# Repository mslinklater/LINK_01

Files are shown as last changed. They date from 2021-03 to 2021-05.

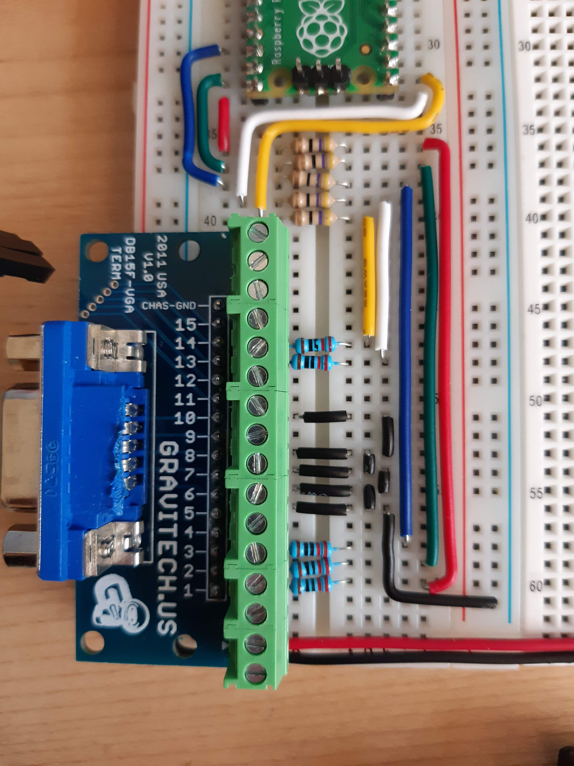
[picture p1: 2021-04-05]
images/20210330_164638.jpg

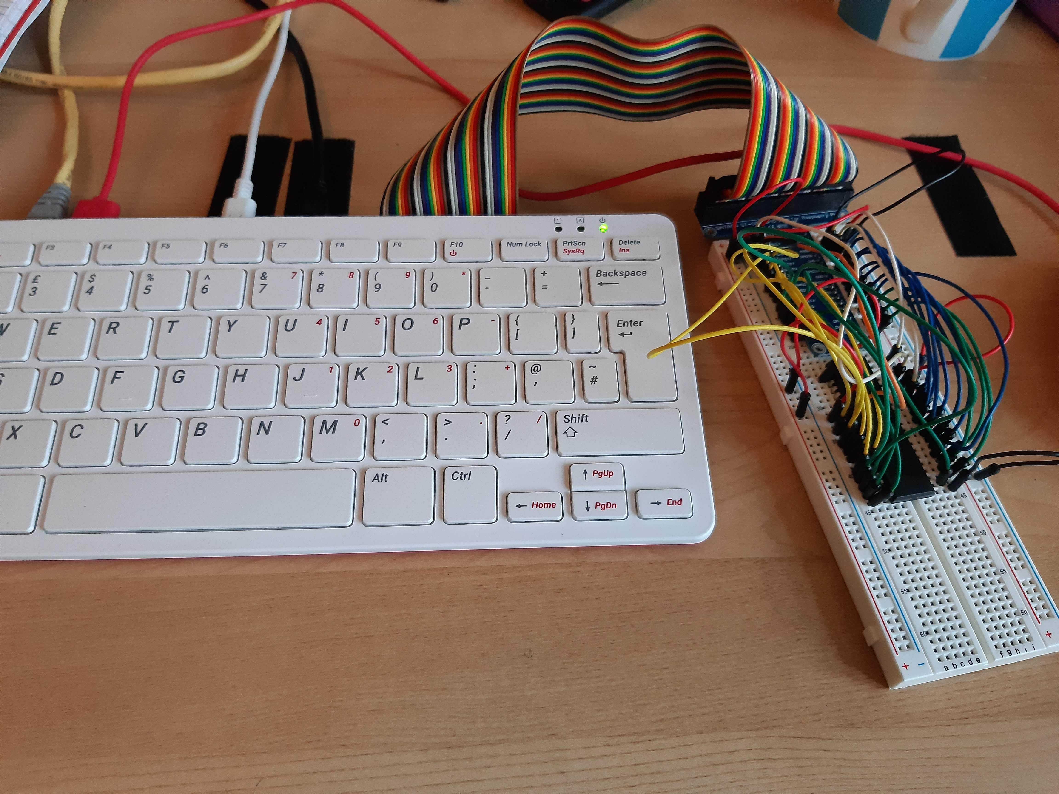
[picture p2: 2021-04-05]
images/20210210_091011.jpg

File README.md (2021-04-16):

# LINK_01
The LINK_01 machine

## What is LINK_01 ?

LINK_01 is my first hombrew computer. At the moment I'm not sure it will work... but I hope it will.

## Key Features

* To explore 8-bit CPU technology by leveraging modern cheap microcontrollers.
* To be fully software upgradeable
* To let the microcontroller do the heavy lifting with I/O
* To use modern compiler and debugging tools
* To have fun programming the 6502

# Starting the monitor

> minicom -b 115200 -o -D /dev/serial0

ctrl-a q to quit

# Writing the EEPROM

> minipro -p AT28C64B -w ROMFILE

# Outputting a ROM

> hexdump -C FILE

# Raspberry Pi pins

|pin|use|
|---|---|
|6|GND (board)|
|8|UART-TX|
|10|UART-RX|
|18|SWDIO|
|20|GND|
|22|SWCLK|

# Pico pins

|use|GPIO|pin||pin|GPIO|use|
|---|---|---|---|---|---|---|
|UART TX|0|1|###|40|-|5V IN|
|UART RX|1|2|###|39|-||
|GND|-|3|###|38|-|GND|
||2|4|###|37|-||
||3|5|###|36|-||
||4|6|###|35|-||
||5|7|###|34|28|6502 PHI-2|
|GND|-|8|###|33|-|GND|
||6|9|###|32|27|6502 RESB|
||7|10|###|31|26|6502 BE|
||8|11|###|30|-||
||9|12|###|29|22|6502 IRQB|
|GND|-|13|###|28|-|GND|
|6502 RWB|10|14|###|27|21|6502 NMIB|
|SHIFTER OUT|11|15|###|26|20|SHIFTER OE|
|SHIFTER IN|12|16|###|25|19|SHIFTER S0|
|VGA-B|13|17|###|24|18|SHIFTER S1|
|GND|-|18|###|23|-|GND|
|VGA-G|14|19|###|22|17|VGA v-sync|
|VGA-R|15|20|###|21|16|VGA h-sync|

Pin counts (available 28)

UART 2
VGA 5
6502 5
Shifter 5

# VGA pins

|pin|use|
|---|---|
|1|R|
|2|G|
|3|B|
|4|-|
|5|GND|
|6|GND|
|7|GND|
|8|GND|
|9|-|
|10|GND|
|11|-|
|12|-|
|13|H-SYNC|
|14|V-SYNC|
|15|-|

# 65c02 pins

|use|pin||pin|use|
|---|---|---|---|---|
|VPB|1|XXX|40|RESB|
|RDY|2|XXX|39|PHI2O|
|PHI1O|3|XXX|38|SOB|
|IRQB|4|XXX|37|PHI2|
|MLB|5|XXX|36|BE|
|NMIB|6|XXX|35|NC|
|SYNC|7|XXX|34|RWB|
|VDD|8|XXX|33|D0|
|A0|9|XXX|32|D1|
|A1|10|XXX|31|D2|
|A2|11|XXX|30|D3|
|A3|12|XXX|29|D4|
|A4|13|XXX|28|D5|
|A5|14|XXX|27|D6|
|A6|15|XXX|26|D7|
|A7|16|XXX|25|A15|
|A8|17|XXX|24|A14|
|A9|18|XXX|23|A13|
|A10|19|XXX|22|A12|
|A11|20|XXX|21|VSS|

# Voltage Shifter 1 - TSX0108E

|pin|function|
|---|---|
|1|6502 PHI2|
|2|6502 RESB|
|3|6502 BE|
|4|6502 IRQB|
|5|6502 NMIB|
|6|SHIFTER OE|
|7|SHIFTER S0|
|8|SHIFTER S1|

# Voltage Shifter 2 - TSX0108E

|pin|function|
|---|---|
|1|SHIFTER IN|
|2|SHIFTER OUT|
|3|6502 RWB|
|4||
|5||
|6||
|7||
|8||

# Shift register - SN74F299N

|use|pin|---|pin|use|
|---|---|---|---|---|
||1|###|20||
||2|###|19||
||3|###|18||
||4|###|17||
||5|###|16||
||6|###|15||
||7|###|14||
||8|###|13||
||9|###|12||
||10|###|11||

# AT28C64B EEPROM

|pin|num|---|num|pin|
|---|---|---|---|---|
|NC|1|###|28|VCC|
|A12|2|###|27|~WE|
|A7|3|###|26|NC|
|A6|4|###|25|A8|
|A5|5|###|24|A9|
|A4|6|###|23|A11|
|A3|7|###|22|~OE|
|A2|8|###|21|A10|
|A1|9|###|20|~CE|
|A0|10|###|19|I/O7|
|I/O0|11|###|18|I/O6|
|I/O1|12|###|17|I/O5|
|I/O2|13|###|16|I/O4|
|GND|14|###|15|I/O3|

# AS6C6264 8K RAM

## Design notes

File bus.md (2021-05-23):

# 5V Bus

|ID|Count|Description|
|---|---|---|
|GND|1|Ground 0V - VDD|
|5V|1|5V Supply - VCC|
|A0-A15|16|Address lines 0-15|
|D0-D7|8|Data lines 0-7|
|R/~W|1|Rear/Write - from 6502 or Pico|
|~R|1|Read pulse|
|~W|1|Write pulse|
|CLK|1|Clock - from Pico|
|RESET|1|6502 Reset - from Pico|
|NMIB|1|Non-maskable interrupt - pulled up|
|IRQB|1|Interrupt request - pulled up|
|FREE|3|Left to assign|
|TOTAL|36|Max lines on the veroboard|

If things become tight the ~R and ~W channels could be retired. This would mean those signals would need to be generated locally per module rather than as part of the 6502 module.

# 3V3 Bus

|ID|Count|Description|
|---|---|---|
|GND|1|Ground 0V VDD|
|3V3|1|3.3V Supply VCC|
|B0-B15|16|General purpose signals|
|TOTAL|18||

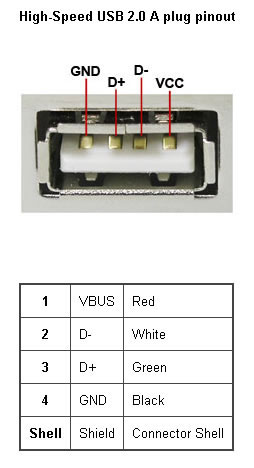
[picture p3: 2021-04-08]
schematics/chips/USB-A-TERM_4.jpg

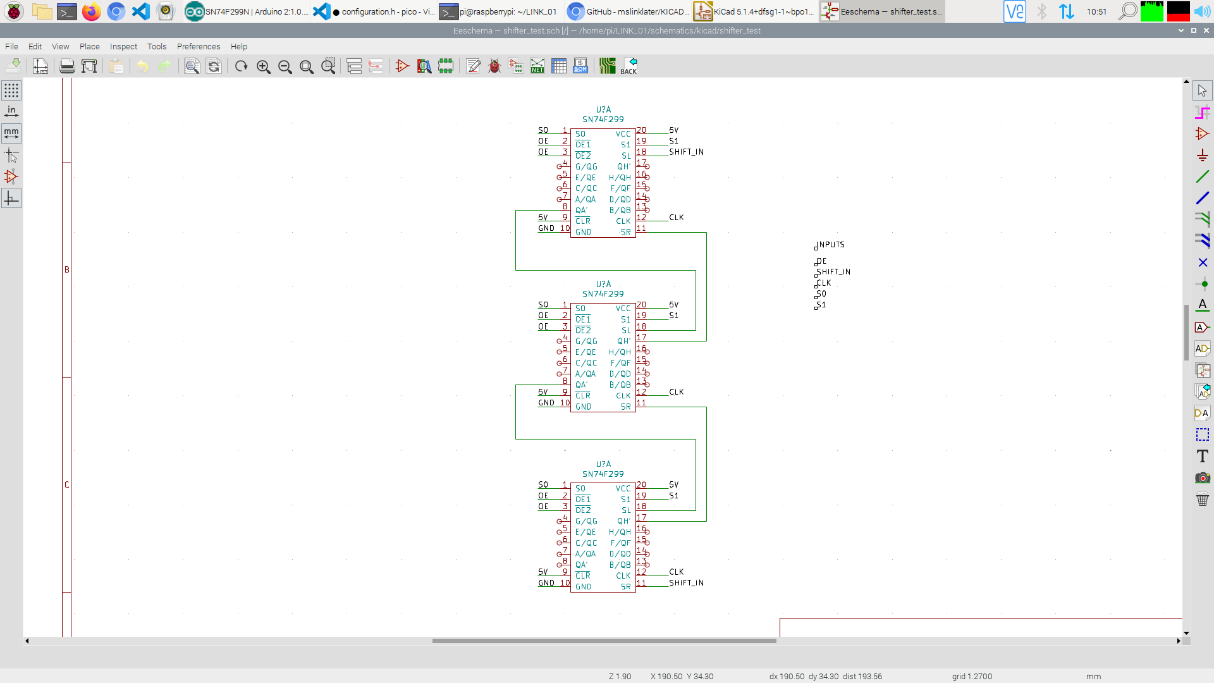
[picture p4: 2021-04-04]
images/shifter.png

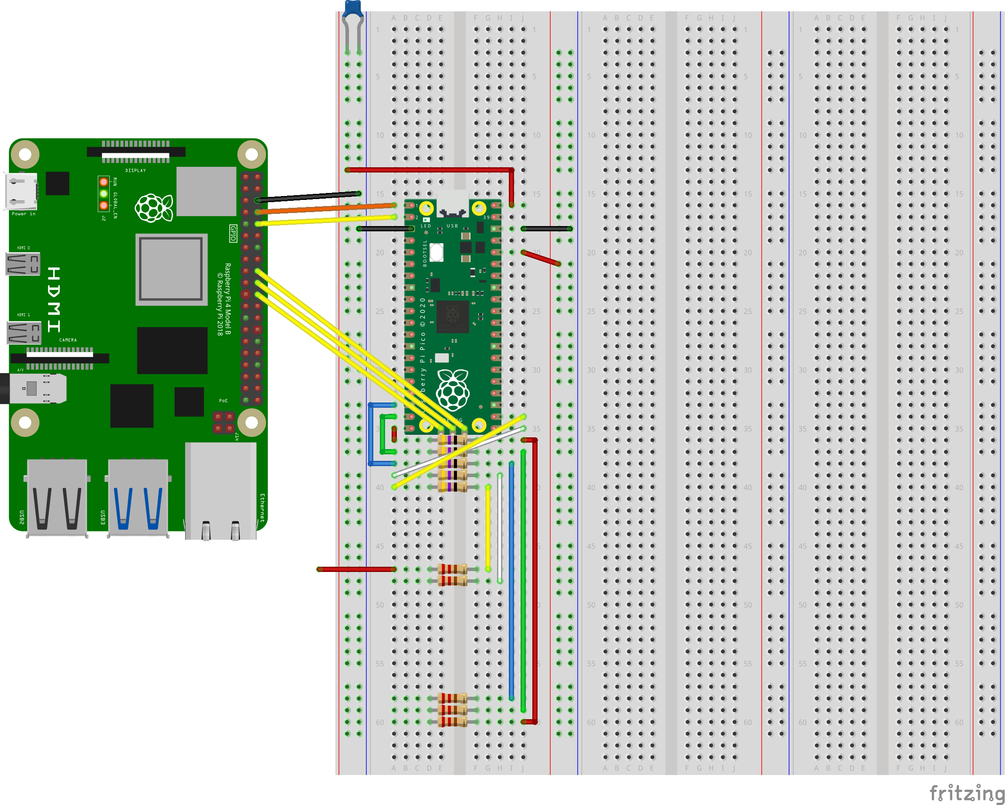
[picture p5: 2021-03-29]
images/LINK_01_bb.png

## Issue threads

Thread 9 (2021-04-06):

Fix UART comms

mslinklater, 2021-04-06:
No idea why it's stopped working. Sample programs are also hosed so probably a hardware thing.

mslinklater, 2021-04-16:
UART is working but not doing line feeds... printf is though.. scope them and find the difference,.

Closed 2021-04-30.

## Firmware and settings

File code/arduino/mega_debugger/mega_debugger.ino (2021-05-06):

#include <LiquidCrystal.h>

#define NUM_READ_PINS 32
#define NUM_DELAY_VALUES 4
#define NUM_DISPLAY_MODES 2
#define NUM_BUTTONS 3
#define BUTTON_DEBOUNCE 50
#define CLOCK_PIN 2

#define LCD_RS 8
#define LCD_EN 9
#define LCD_D4 10
#define LCD_D5 11
#define LCD_D6 12
#define LCD_D7 13

const String mnemonics[256] = {
  "BRK", "ORA(zp,x)", "", "", "TSB zp", "ORA zp", "ASL zp", "RMB0 zp", "PHP", "ORA #", "ASL A", "", "TSB a", "ORA $", "ASL $", "BBR0 r",
  "BPL r", "ORA (zp),y", "ORA (zp)", "", "TRB zp", "ORA zp,x", "ASL zp,x", "RMB1 zp", "CLC", "ORA $,y", "INC A", "", "TRB $", "ORA $,x", "ASL $,x", "BBR1 r",
  "JSR a", "AND (zp,x)", "", "", "BIT zp", "AND zp", "ROL zp", "RMB2 zp", "PLP", "AND #", "ROL A", "", "BIT $", "AND $", "ROL $", "BBR2 r",
  "BMI r", "AND (zp),y", "AND (zp)", "", "BIT zp,x", "AND zp,x", "ROL zp,x", "RMB3 zp", "SEC I", "AND $,y", "DEC A", "", "BIT $,x", "AND $,x", "ROL $,x", "BBR3 r",
  "RTI s", "EOR (zp,x)", "", "", "", "EOR zp", "LSR zp", "RMB4 zp", "PHA", "EOR #", "LSR A", "", "JMP $", "EOR $", "LSR $", "BBR4 r",
  "BVC r", "EOR (zp),y", "EOR (zp)", "", "", "EOR zp,x", "LSR zp,x", "RMB5 zp", "CLI", "EOR $,y", "PHY", "", "", "EOR $,x", "LSR $", "BBR5 r",
  "RTS s", "ADC (zp,x)", "", "", "STZ zp", "ADC zp", "ROR zp", "RMB6 zp", "PLA", "ADC #", "ROR A", "", "JMP ($)", "ADC $", "ROR $", "BBR6 r",
  "BVS r", "ADC (zp),y", "ADC (zp)", "", "STZ zp,x", "ADC zp,x", "ROR zp,x", "RMB7 zp", "SEI", "ADC $,y", "PLY", "", "JMP ($.x)", "ADC $,x", "ROR $,x", "BBR7 r",
  "BRA r", "STA (zp,x)", "", "", "STY zp", "STA zp", "STZ zp", "SMB0 zp", "DEY", "BIT #", "TXA", "", "STY $", "STA $", "STX $", "BBS0 r",
  "BCC r", "STA (zp),y", "STA (zp)", "", "STY zp,x", "STA zp,x", "STZ zp,y", "SMB1 zp", "TYA", "STA $,y", "TSX", "", "STZ $", "STA $,x", "STZ $,x", "BBS1 r",
  "LDY #", "LDA (zp,x)", "LDX #", "", "LDY zp", "LDA zp", "LDX zp", "SMB2 zp", "TAY", "LDA #", "TAX", "", "LDY $", "LDA $", "LDX $", "BBS2 r",
  "BCS r", "LDA (zp),y", "LDA (zp)", "", "LDY zp,x", "LDA zp,x", "LDX zp,y", "SMB3 zp", "CLV", "LDA A,y", "TSX", "", "LDY $,x", "LDA $,x", "LDX $,x", "BBS3 r",
  "CPY #", "CMP (zp,x)", "", "", "CPY zp", "CMP zp", "DEC zp", "SMB4 zp", "INY", "CMP #", "DEX", "WAI", "CPY $", "CMP $", "DEC $", "BBS4 r",
  "BNE r", "CMP (zp),y", "CMP (zp)", "", "", "CMP zp,x", "DEC zp,x", "SMB5 zp", "CLD", "CMP $,y", "PHX", "STP", "", "CMP $,x", "DEC $,x", "BBS5 r",
  "CPX #", "SBC (zp,x)", "", "", "CPX zp", "SBC zp", "INC zp", "SMB6 zp", "INX", "SBC #", "NOP", "", "CPX $", "SBC $", "INC $", "BBS6 r",
  "BEQ r", "SBC (zp),y", "SBC (zp)", "", "", "SBC zp,x", "INC zp,x", "SMB7 zp", "SED", "SBC $,y", "PLX", "", "", "SBC $,x", "INC $,x", "BBS7 r"
};

const String symbolfile = "";

// input pins
const int read_pins[NUM_READ_PINS] = { 
  23, 25, 27, 29, 31, 33, 35, 37,
  39, 41, 43, 45, 47, 49, 51, 53,
  22, 24, 26, 28, 30, 32, 34, 36,
  38, 40, 42, 44, 46, 48, 50, 52 };

#define RW_PIN 24
#define SYNC_PIN 25
#define CPU_BE_PIN 26

int cached_read_pins[NUM_READ_PINS];

// button pins
const int button_pins[NUM_BUTTONS] = {
  7, 6, 5};
int last_button_state[NUM_BUTTONS] = {
  LOW, LOW, LOW};
unsigned long button_debounce[NUM_BUTTONS];

// clock interrupt

LiquidCrystal lcd(LCD_RS, LCD_EN, LCD_D4, LCD_D5, LCD_D6, LCD_D7);

int displayMode = 0;

String command = "";

void setup()
{
  // input pins
  for(int i=0 ; i<NUM_READ_PINS ; i++)
  {
    pinMode(read_pins[i], INPUT);
  }

  // button pins
  for(int i=0 ; i<NUM_BUTTONS ; i++)
  {
    pinMode(button_pins[i], INPUT);
  }

  // clear LCD
  lcd.begin(16,2);

  // clock interrupt
  pinMode(CLOCK_PIN, INPUT);
  attachInterrupt(0, onClock, RISING);

  Serial.begin(115200);
}

void onClock()
{
  display();
}

void draw_hex()
{
  lcd.setCursor(0,0);

  int pin=0;
  char buffer [32];

  // address
  int addrVal = 0;
  for(int nibble=0 ; nibble<4 ; nibble++)
  {
    for(int bit=0 ; bit < 4 ; bit++)
    {
      addrVal <<= 1;
      addrVal += cached_read_pins[pin] == HIGH ? 1 : 0;
      pin++;
    }
  }

  // data
  pin = 16;
  int dataVal = 0;
  for(int nibble=0 ; nibble<2 ; nibble++)
  {
    for(int bit=0 ; bit < 4 ; bit++)
    {
      dataVal <<= 1;
      dataVal += cached_read_pins[pin] == HIGH ? 1 : 0;
      pin++;
    }
  }
  sprintf(buffer, "A:0x%04X D:0x%02X ", addrVal, dataVal);
  lcd.print(buffer);
  Serial.print(buffer);

  String instruction = "          ";
  if(digitalRead(read_pins[SYNC_PIN]) == HIGH)
  {
    instruction = mnemonics[dataVal];
  }
  else
  {
    switch(addrVal)
    {
      case 0xfffc:
      case 0xfffd:
        instruction = "RESET";
        break;
    }
  }

  // R/W
  sprintf(buffer, "%s%s %s", digitalRead(read_pins[RW_PIN]) == HIGH ? "R" : "W",digitalRead(read_pins[CPU_BE_PIN]) == HIGH ? "B" : "b", instruction.c_str());
  lcd.setCursor(0,1);
  lcd.print(buffer); 
  Serial.println(buffer);
}

void draw_raw()
{
  char buffer [32];
  
  // draw raw inputs on 32 pins
  lcd.setCursor(0,0);
  sprintf(buffer, "%d%d%d%d%d%d%d%d%d%d%d%d%d%d%d%d",
            cached_read_pins[0],
            cached_read_pins[1],
            cached_read_pins[2],
            cached_read_pins[3],
            cached_read_pins[4],
            cached_read_pins[5],
            cached_read_pins[6],
            cached_read_pins[7],
            cached_read_pins[8],
            cached_read_pins[9],
            cached_read_pins[10],
            cached_read_pins[11],
            cached_read_pins[12],
            cached_read_pins[13],
            cached_read_pins[14],
            cached_read_pins[15]);
  lcd.print(buffer);
  lcd.setCursor(0,1);
  sprintf(buffer, "%d%d%d%d%d%d%d%d%d%d%d%d%d%d%d%d",
            cached_read_pins[16],
            cached_read_pins[17],
            cached_read_pins[18],
            cached_read_pins[19],
            cached_read_pins[20],
            cached_read_pins[21],
            cached_read_pins[22],
            cached_read_pins[23],
            cached_read_pins[24],
            cached_read_pins[25],
            cached_read_pins[26],
            cached_read_pins[27],
            cached_read_pins[28],
            cached_read_pins[29],
            cached_read_pins[30],
            cached_read_pins[31]);
  lcd.print(buffer);
 
}

void display()
{
  if(command.length() > 0)
    return;

  cache_pins();
  
  // display to LCD
  switch(displayMode)
  {
  case 0:
    draw_hex();
    break;
  case 1:
    draw_raw();
    break;
  }
}

void cache_pins()
{
  for(int i=0 ; i<NUM_READ_PINS ; i++)
  {
    cached_read_pins[i] = digitalRead(read_pins[i]);
  }
}

void loop()
{
  if(command.length() > 0)
  {
    // display command
    lcd.begin(16,2);
    lcd.print(command);
    delay(750);  // need to get rid of this too
    command = "";
  }

  // read button 0
  int val = digitalRead(button_pins[0]);
  if((val == HIGH) && (last_button_state[0] == LOW))
  {
    if(button_debounce[0] + BUTTON_DEBOUNCE < millis())
    {
      displayMode++;
      if(displayMode >= NUM_DISPLAY_MODES)
        displayMode = 0;
      switch(displayMode)
      {
      case 0: 
        command="Display - HEX"; 
        break;
      case 1: 
        command="Display - RAW"; 
        break;
      }
      button_debounce[0] = millis();
    }
  }
  last_button_state[0] = val;

  // read button 0
  val = digitalRead(button_pins[1]);
  if((val == HIGH) && (last_button_state[1] == LOW))
  {
    if(button_debounce[1] + BUTTON_DEBOUNCE < millis())
    {
      display();
      button_debounce[1] = millis();
    }
  }
  last_button_state[1] = val;
  
  delay(10);
}

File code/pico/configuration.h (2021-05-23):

#define UART_ID uart0
#define UART_BAUD_RATE 115200
#define UART_DATA_BITS 8
#define UART_STOP_BITS 1
#define UART_PARITY UART_PARITY_NONE

// serial comms
#define UART_TX_PIN 0
#define UART_RX_PIN 1

// 8-bit bus
#define IC6502_PHI2_PIN 28
#define IC6502_RESB_PIN 27

/// Bus Enable
///
/// LOW - high impedance
/// HIGH - bus enabled
#define IC6502_BE_PIN 26
#define IC6502_IRQB_PIN 22
#define IC6502_NMIB_PIN 21
#define IC6502_RWB_PIN 10

// Shifter complex
#define SHIFTER_OE_PIN 20
#define SHIFTER_S0_PIN 19
#define SHIFTER_S1_PIN 18
#define SHIFTER_IN_PIN 12
#define SHIFTER_OUT_PIN 11
#define SHIFTER_CLK_PIN 9
#define SHIFTER_BUS_DIR_PIN 8
#define SHIFTER_BUS_OE_PIN 7

// 3V3 bus

#define VGA_VSYNC 17
#define VGA_HSYNC 16
#define VGA_R 15
#define VGA_G 14
#define VGA_B 13
#define UNASSIGNED_1 8
#define UNASSIGNED_2 7
#define UNASSIGNED_3 6
#define UNASSIGNED_4 5
#define UNASSIGNED_5 4
#define UNASSIGNED_6 3
#define UNASSIGNED_7 2

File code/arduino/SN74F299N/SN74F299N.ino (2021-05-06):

/*
  SN74F299N explorer
  */

/*
MODE  CLR S1  S0  OE1 OE2 CLK SL  SR  QA  QB  QC  QD  QE  QF  QG  QH  QA' QH'

Clear L   X   L   L   L   X   X   X   L   L   L   L   L   L   L   L   L   L
      L   L   X   L   L   X   X   X   L   L   L   L   L   L   L   L   L   L
      L   H   H   X   X   X   X   X   X   X   X   X   X   X   X   X   L   L
      
Hold  H   L   L   L   L   X   X   X   QA0 QB0 QC0 QD0 QE0 QF0 QG0 QH0 QA0 QH0
      H   X   X   L   L   L   X   X   QA0 QB0 QC0 QD0 QE0 QF0 QG0 QH0 QA0 QH0   <
      
Shift H   L   H   L   L   ^   X   H   H   QAn QBn QCn QDn QEn QFn QGn H   QGn
Right H   L   H   L   L   ^   X   L   L   QAn QBn QCn QDn QEn QFn QGn L   QGn

Shift H   H   L   L   L   ^   H   X   QBn QCn QDn QEn QFn QGn QHn H   QBn H     <
Left  H   H   L   L   L   ^   L   X   QBn QCn QDn QEn QFn QGn QHn L   QBn L     <

Load  H   H   H   X   X   ^   X   X   a   b   c   d   e   f   g   h   a   h     <
*/

#define PIN_S0 0
#define PIN_OE1 1
#define PIN_OE2 2
#define PIN_G 3
#define PIN_E 4
#define PIN_C 5
#define PIN_A 6
#define PIN_QA 7
#define PIN_CLR 8

#define PIN_SR 9
#define PIN_CLK 10
#define PIN_B 11
#define PIN_D 12
#define PIN_F 13
#define PIN_H 14
#define PIN_QH 15
#define PIN_SL 16
#define PIN_S1 17

int pin[18] = {
  52, 50, 48, 46, 44, 42, 40, 38, 36,
  37, 39, 41, 43, 45, 47, 49, 51, 53
};

void setup()
{
  Serial.begin(112500);

  // pin directions
  pinMode(pin[PIN_S0], OUTPUT);
  pinMode(pin[PIN_OE1], OUTPUT);
  pinMode(pin[PIN_OE2], OUTPUT);
  pinMode(pin[PIN_CLR], OUTPUT);
  pinMode(pin[PIN_SR], OUTPUT);
  pinMode(pin[PIN_CLK], OUTPUT);
  pinMode(pin[PIN_SL], OUTPUT);
  pinMode(pin[PIN_S1], OUTPUT);
  pinMode(pin[PIN_QA], INPUT);
  pinMode(pin[PIN_QH], INPUT);

  set_bus(INPUT);  
}

void set_bus(int value)
{
  pinMode(pin[PIN_A], value);
  pinMode(pin[PIN_B], value);
  pinMode(pin[PIN_C], value);
  pinMode(pin[PIN_D], value);
  pinMode(pin[PIN_E], value);
  pinMode(pin[PIN_F], value);
  pinMode(pin[PIN_G], value);
  pinMode(pin[PIN_H], value);
}

void set_bus_value(int value)
{
  digitalWrite(pin[PIN_A], value & 0x01);
  digitalWrite(pin[PIN_B], value & 0x02);
  digitalWrite(pin[PIN_C], value & 0x04);
  digitalWrite(pin[PIN_D], value & 0x08);
  digitalWrite(pin[PIN_E], value & 0x10);
  digitalWrite(pin[PIN_F], value & 0x20);
  digitalWrite(pin[PIN_G], value & 0x40);
  digitalWrite(pin[PIN_H], value & 0x80);
}

int read_bus_value()
{
  int out = 0;
  out += digitalRead(pin[PIN_A]) == HIGH ? 0x01 : 0;
  out += digitalRead(pin[PIN_B]) == HIGH ? 0x02 : 0;
  out += digitalRead(pin[PIN_C]) == HIGH ? 0x04 : 0;
  out += digitalRead(pin[PIN_D]) == HIGH ? 0x08 : 0;
  out += digitalRead(pin[PIN_E]) == HIGH ? 0x10 : 0;
  out += digitalRead(pin[PIN_F]) == HIGH ? 0x20 : 0;
  out += digitalRead(pin[PIN_G]) == HIGH ? 0x40 : 0;
  out += digitalRead(pin[PIN_H]) == HIGH ? 0x80 : 0;
  
  return out;
}

void clock()
{
  digitalWrite(pin[PIN_CLK], LOW);
  digitalWrite(pin[PIN_CLK], HIGH);
}

void load()
{
  digitalWrite(pin[PIN_CLR], HIGH);
  digitalWrite(pin[PIN_S1], HIGH);
  digitalWrite(pin[PIN_S0], HIGH);
  clock();
}

void hold()
{
  digitalWrite(pin[PIN_CLR], HIGH);
  digitalWrite(pin[PIN_S0], LOW);
  digitalWrite(pin[PIN_S1], LOW);
  digitalWrite(pin[PIN_OE1], LOW);
  digitalWrite(pin[PIN_OE2], LOW);
}

void left()
{
  digitalWrite(pin[PIN_CLR], HIGH);
  digitalWrite(pin[PIN_S1], HIGH);
  digitalWrite(pin[PIN_S0], LOW);
  digitalWrite(pin[PIN_OE1], LOW);
  digitalWrite(pin[PIN_OE2], LOW);
//  digitalWrite(pin[PIN_SL], HIGH);
  clock();  
}

void right()
{
  digitalWrite(pin[PIN_CLR], HIGH);
  digitalWrite(pin[PIN_S1], LOW);
  digitalWrite(pin[PIN_S0], HIGH);
  digitalWrite(pin[PIN_OE1], LOW);
  digitalWrite(pin[PIN_OE2], LOW);
//  digitalWrite(pin[PIN_SR], HIGH);
  clock();  
}

void read_random_value()
{
  // set bus to random value
  
  int write_value = random(0,256);
  
  set_bus(OUTPUT);
  set_bus_value(write_value);
  
  load();
  
  // hold the value
  hold();
    
  // set bus to write
  set_bus(INPUT);
  
  // roll value and rebuild number
  int read_value = 0;
  for(int i=0 ; i<8 ; i++)
  {
    read_value <<= 1;
    read_value += digitalRead(pin[PIN_H]) == HIGH ? 1 : 0;
    right();
  }
  
  char buffer[32];
  sprintf(buffer, "bus write %02x shift read %02x", write_value, read_value);  
  Serial.println(buffer);
}

void write_random_value()
{
  set_bus(INPUT);

  int write_value = random(0,256);
  
  // shift in a value

  for(int i=0 ; i<8 ; i++)
  {
    digitalWrite(pin[PIN_SR], (write_value & (0x80>>i)) == 0 ? LOW : HIGH );
    right();
  }
  
  // read value from bus
  int read_value = read_bus_value();

  char buffer[32];
  sprintf(buffer, "shift write %02x bus read %02x", write_value, read_value);
  Serial.println(buffer);
}

void loop()
{
  Serial.println("---");
  read_random_value();
  write_random_value();
  delay(1000);
}

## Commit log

2021-03-20 Added uart stuff
    [configuration.h]
2021-03-29 6502 PHI-2 BE & RESB working.
    [configuration.h]
2021-03-29 Added Fritzing
    [LINK_01.fzz]
2021-03-31 Added 6502 IRQ pins
    [configuration.h]
2021-04-01 Shifter arduino code
2021-04-02 Added shifter test KICAD
    [shifter_test.kicad_pcb, shifter_test.sch]
2021-04-04 Added full system kicad and a shifter pin definitions
    [FullSystem.kicad_pcb, FullSystem.sch, configuration.h]
2021-04-05 Added system and bus controllers fullsystem schema
    [FullSystem.sch, configuration.h]
2021-04-08 Added EEPROM arduino stuff
2021-04-18 Working RAM
    [configuration.h]
2021-04-18 Started on UART comms
2021-04-23 Started mega debugger schema
    [MegaDebugger.kicad_pcb, MegaDebugger.sch]
2021-04-28 Improvements to mega debugger. Working again.
    [MegaDebugger.sch]
2021-05-06 Arduino shift code done
    [configuration.h]
2021-05-06 mega-debugger now reads on left button
2021-05-23 Added pins for bus transceivers
    [configuration.h]
